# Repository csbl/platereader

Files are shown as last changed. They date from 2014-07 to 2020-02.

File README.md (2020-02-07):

## Miniaturized plate reader designs
This repository provides all the materials needed to assemble a miniaturized plate reader for measuring optical density in 96-well plates. 

Code is available at: https://github.com/csbl/PlateReaderCode

-- 
### File Descriptions
* Assembly Instructions.docx -- Instructions for assembling PCBs, loading code onto Arduinos, and running experiments.
* Parts List.xlsx -- Quantity, pricing, and availability information for all electrical and structural components.
* schematics
    + Frame_Drawings -- SolidWorks technical drawings for machining the aluminum frames.
    + PCBs -- Layout files for three printed circuit boards:  the emitter/detector layout boards (EmitterDetector), the controller shield for an Arduino Mega (MegaShield), and a breakout board for the XBee wireless chip (XBeeBreakoutBoard).
        - .pcb files for ExpressPCB software (http://expresspcb.com/).  We ordered our boards directly from this vendor using their free software.
        - To order boards from other vendors, we have included folders with Gerber files.  These files were provided by ExpressPCB.  Unfortunately, we have not ordered boards using the drawings, so we cannot guarantee their validity.  The file descriptions are:
            * .SLK = top silkscreen layer
            * .SMT = top solder mask layer
            * .TOP = top copper layer
            * .BOT = bottom copper layer
            * .SMB = bottom solder mask layer
            * .DRI = drill file
            * .OLN = board outline

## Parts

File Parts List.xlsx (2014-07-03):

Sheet: Total
ID | Part Description | Price per Part | Number Parts | TOTAL | Link
Emitter and Detector PCBs
1 | Emitter and Detector PCBs | $52.75 | 2 | $105.50 | Computed for 2 boards
2 | Phototransistors | $0.24 | 100 | $24.00 | http://www.digikey.com/product-search/en?x=0&y=0&lang=en&site=us&KeyWords=475-1080-ND
3 | Emitters | $0.65 | 100 | $65.00 | http://www.digikey.com/product-search/en?WT.z_header=search_go&lang=en&site=us&x=0&y=0&formaction=on
4 | Ribbon cable connectors | $0.84 | 4 | $3.36 | http://www.digikey.com/product-search/en?vendor=0&keywords=MKC14E-ND
5 | Ribbon cable (price per foot) | $0.65 | 4 | $2.60 | http://www.digikey.com/product-detail/en/3355%2F14%20100/MB14G-100-ND/1107667
6 | Multiplexers (for Emitter Detector PCBs) | $2.22 | 4 | $8.88 | http://www.digikey.com/product-detail/en/MAX4617CPE%2B/MAX4617CPE%2B-ND/1780285
7 | Ribbon cable connectors (mounted on boards) | $2.65 | 2 | $5.30 | http://www.digikey.com/product-search/en?vendor=0&keywords=MHB14K-ND
Arduino Mega Sheild
8 | Arduino Mega | $44.45 | 1 | $44.45
9 | MicroSD breakout board | $14.95 | 1 | $14.95 | https://www.adafruit.com/product/254
10 | RTC | $9.00 | 1 | $9.00 | https://www.adafruit.com/product/264
11 | AFE | $10.80 | 1 | $10.80 | http://www.digikey.com/product-detail/en/LMP90100MH%2FNOPB/LMP90100MH%2FNOPB-ND/2514654
12 | Chip for VR | $0.92 | 1 | $0.92 | http://www.digikey.com/product-detail/en/UA723CN/296-11104-5-ND/382232
13 | 4.99K resistor (VR) | $0.10 | 1 | $0.10 | http://www.digikey.com/product-detail/en/MFR-25FBF52-4K99/4.99KXBK-ND/13161
14 | 1.5 K resistor (VR) | $0.15 | 1 | $0.15 | http://www.digikey.com/product-detail/en/RNF14FTD1K50/RNF14FTD1K50CT-ND/1975030
15 | 4.3 resistor (VR) | $0.10 | 1 | $0.10 | http://www.digikey.com/product-detail/en/CFR-25JB-52-4R3/4.3QBK-ND/1831
16 | 2.15K resistor (VR) | $0.15 | 1 | $0.15 | http://www.digikey.com/product-detail/en/RNF14FTD2K15/RNF14FTD2K15CT-ND/1975040
17 | Capacitor (VR) | $0.30 | 1 | $0.30 | http://www.digikey.com/product-detail/en/K101K10X7RF5UH5/BC2657CT-ND/2356871
18 | Capacitor (VR) | $0.50 | 1 | $0.50 | http://www.digikey.com/product-search/en?WT.z_header=search_go&lang=en&site=us&x=0&y=0&formaction=on
19 | Power Cord | $12.30 | 1 | $12.30 | http://www.digikey.com/product-search/en?WT.z_header=search_go&lang=en&site=us&x=0&y=0&formaction=on
20 | Red LED | $0.50 | 1 | $0.50 | http://www.digikey.com/product-search/en?WT.z_header=search_go&lang=en&site=us&x=0&y=0&formaction=on
21 | Resistor 1 | $0.10 | 1 | $0.10 | http://www.digikey.com/product-detail/en/MFR-25FBF52-402R/402XBK-ND/12921
22 | Resistor 2 | $0.10 | 1 | $0.10 | http://www.digikey.com/product-detail/en/MFR-25FBF52-301R/301XBK-ND/12889
23 | Resistor 3 | $0.10 | 1 | $0.10 | http://www.digikey.com/product-detail/en/MFR-25FBF52-221R/221XBK-ND/12863
24 | Resistor 4 | $0.10 | 1 | $0.10 | http://www.digikey.com/product-detail/en/MFR-25FBF52-178R/178XBK-ND/12845
25 | SD card | $12.95 | 1 | $12.95 | https://www.sparkfun.com/products/11609
26 | MAX 4617 Multiplexer (Resistors) | $2.08 | 1 | $2.08 | http://www.digikey.com/product-detail/en/MAX4617CUE%2B/MAX4617CUE%2B-ND/1016407
27 | Ribbon cable connectors | $2.65 | 2 | $5.30 | http://www.digikey.com/product-search/en?WT.z_header=search_go&lang=en&site=us&x=0&y=0&formaction=on
28 | 200 resistor for LED | $0.08 | 1 | $0.08 | http://www.digikey.com/product-detail/en/CF14JT200R/CF14JT200RCT-ND/1830333
29 | 100K resistor (VR) | $0.44 | 1 | $0.44 | http://www.digikey.com/product-detail/en/HHV-25FR-52-100K/100KGACT-ND/2813157
30 | Female header for Xbee | $1.00 | 1 | $1.00 | https://www.sparkfun.com/products/8272
31 | Header (40 pins per strip) | $1.50 | 1 | $1.50 | https://www.sparkfun.com/products/116
32 | Power Switch | $1.50 | 1 | $1.50 | https://www.sparkfun.com/products/102
33 | Barrel Jack | $1.25 | 1 | $1.25 | https://www.sparkfun.com/products/119
34 | Xbee | $25.95 | 2 | $51.90 | https://www.sparkfun.com/products/11217
35 | Xbee PCB | $38.48 | 1 | $38.48
36 | Raspberry Pi | $39.95 | 1 | $39.95
 |  |  | TOTAL | $465.69

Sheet: Controller Board
ID | Part Description | Price per Part | Number Parts | TOTAL
1 | Arduino Mega | $44.45 | 1 | $44.45
2 | MicroSD breakout board | $14.95 | 1 | $14.95 | https://www.adafruit.com/product/254
3 | RTC | $9.00 | 1 | $9.00 | https://www.adafruit.com/product/264
4 | AFE | $10.80 | 1 | $10.80 | http://www.digikey.com/product-detail/en/LMP90100MH%2FNOPB/LMP90100MH%2FNOPB-ND/2514654
5 | Chip for VR | $0.92 | 1 | $0.92 | http://www.digikey.com/product-detail/en/UA723CN/296-11104-5-ND/382232
6 | 4.99K resistor (VR) | $0.10 | 1 | $0.10 | http://www.digikey.com/product-detail/en/MFR-25FBF52-4K99/4.99KXBK-ND/13161
7 | 1.5 K resistor (VR) | $0.15 | 1 | $0.15 | http://www.digikey.com/product-detail/en/RNF14FTD1K50/RNF14FTD1K50CT-ND/1975030
8 | 4.3 resistor (VR) | $0.10 | 1 | $0.10 | http://www.digikey.com/product-detail/en/CFR-25JB-52-4R3/4.3QBK-ND/1831
9 | 2.15K resistor (VR) | $0.15 | 1 | $0.15 | http://www.digikey.com/product-detail/en/RNF14FTD2K15/RNF14FTD2K15CT-ND/1975040
10 | Capacitor (VR) | $0.30 | 1 | $0.30 | http://www.digikey.com/product-detail/en/K101K10X7RF5UH5/BC2657CT-ND/2356871
11 | Capacitor (VR) | $0.50 | 1 | $0.50 | http://www.digikey.com/product-search/en?WT.z_header=search_go&lang=en&site=us&x=0&y=0&formaction=on
12 | Power Cord | $12.30 | 1 | $12.30 | http://www.digikey.com/product-search/en?WT.z_header=search_go&lang=en&site=us&x=0&y=0&formaction=on
13 | Red LED | $0.50 | 1 | $0.50 | http://www.digikey.com/product-search/en?WT.z_header=search_go&lang=en&site=us&x=0&y=0&formaction=on
14 | Resistor 1 | $0.10 | 1 | $0.10 | http://www.digikey.com/product-detail/en/MFR-25FBF52-402R/402XBK-ND/12921
15 | Resistor 2 | $0.10 | 1 | $0.10 | http://www.digikey.com/product-detail/en/MFR-25FBF52-301R/301XBK-ND/12889
16 | Resistor 3 | $0.10 | 1 | $0.10 | http://www.digikey.com/product-detail/en/MFR-25FBF52-221R/221XBK-ND/12863
17 | Resistor 4 | $0.10 | 1 | $0.10 | http://www.digikey.com/product-detail/en/MFR-25FBF52-178R/178XBK-ND/12845
18 | SD card | $12.95 | 1 | $12.95 | https://www.sparkfun.com/products/11609
19 | MAX 4617 Multiplexer (Resistors) | $2.08 | 1 | $2.08 | http://www.digikey.com/product-detail/en/MAX4617CUE%2B/MAX4617CUE%2B-ND/1016407
20 | Ribbon cable connectors | $2.65 | 2 | $5.30 | http://www.digikey.com/product-search/en?WT.z_header=search_go&lang=en&site=us&x=0&y=0&formaction=on
21 | 200 resistor for LED | $0.08 | 1 | $0.08 | http://www.digikey.com/product-detail/en/CF14JT200R/CF14JT200RCT-ND/1830333
22 | 100K resistor (VR) | $0.44 | 1 | $0.44 | http://www.digikey.com/product-detail/en/HHV-25FR-52-100K/100KGACT-ND/2813157
23 | Female header for Xbee | $1.00 | 1 | $1.00 | https://www.sparkfun.com/products/8272
24 | Header (40 pins per strip) | $1.50 | 1 | $1.50 | https://www.sparkfun.com/products/116
25 | Power Switch | $1.50 | 1 | $1.50 | https://www.sparkfun.com/products/102
26 | Barrel Jack | $1.25 | 1 | $1.25 | https://www.sparkfun.com/products/119
27 | Xbee | $25.95 | 1 | $25.95 | https://www.sparkfun.com/products/11217
28 | Xbee PCB | $38.48 | 1 | $38.48 |  | $382.36 for 100 boards
 |  |  |  | $185.15

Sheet: Aluminum Frame
ID | MccMaster-carr ID | Part Description | Price per Unit | Parts per Unit | Parts Needed Per Device | TOTAL
1 | 92185A996 | Type 316 Stainless Steel Socket Head Cap Screw, 10-32 Thread, 2" Length | $8.49 | 10 | 4 | $8.49
2 | 91249A161 | Plate machine screws 6-32 | $10.45 | 50 | 8 | $10.45
3 | 92001A281 | Wing nut 6-32 | $6.65 | 25 | 4 | $6.65
4 | 92510A446 | spacers 6-32 | $0.34 | 1 | 4 | $1.36
5 | 93135A304 | 3/8" 6-32 Nylon Screw | $0.27 | 1 | 4 | $1.08
6 | 93135A305 | 1/2" 6-32 Nylon Screw | $5.23 | 100 | 4 | $5.23
7 | 90295A380 | Nylon Washer no. 6 | $4.04 | 100 | 24 | $4.04
8 | 94639A299 | Nylon Spacer | $7.11 | 100 | 8 | $7.11
9 | 90107A101 | Metal Washers | $4.32 | 100 | 12 | $4.32
10 | 92949A148 | .5" 6-32 botton head | $4.63 | 100 | 8 | $4.63
 |  |  |  |  | TOTAL | $53.36

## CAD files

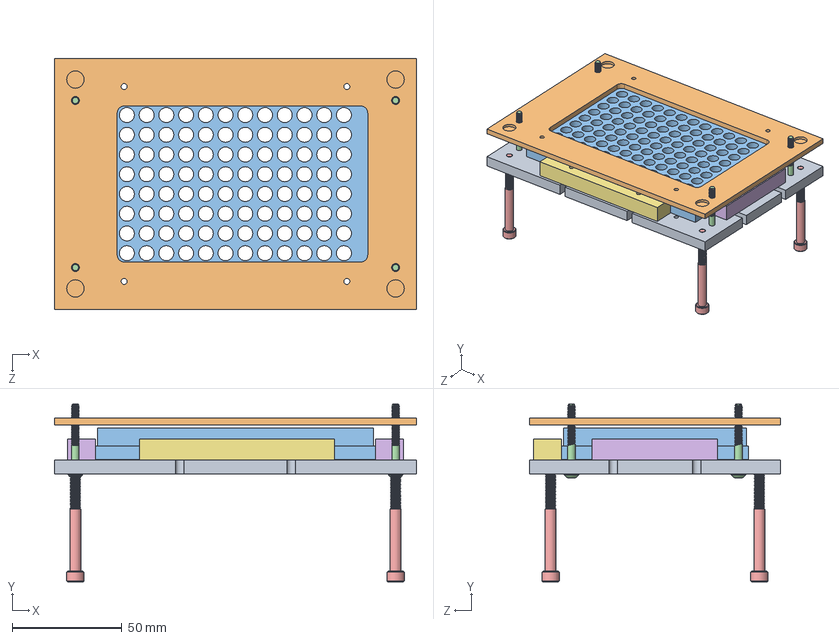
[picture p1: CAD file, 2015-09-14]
schematics/Frame_Drawings/Assem 96 well Plate.SLDASM
165.1 x 81.0 x 114.3 mm
Bottom Plate
Top Plate
96 Well plate
91255A155 Guide_Bolt x 4
92185A996 foot x 4
Side rails amr x 2
Back Stop amr

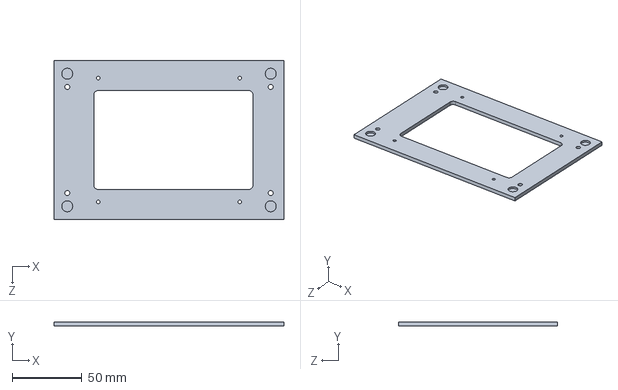
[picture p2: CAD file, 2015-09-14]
schematics/Frame_Drawings/Top Plate.SLDPRT
165.1 x 3.17 x 114.3 mm

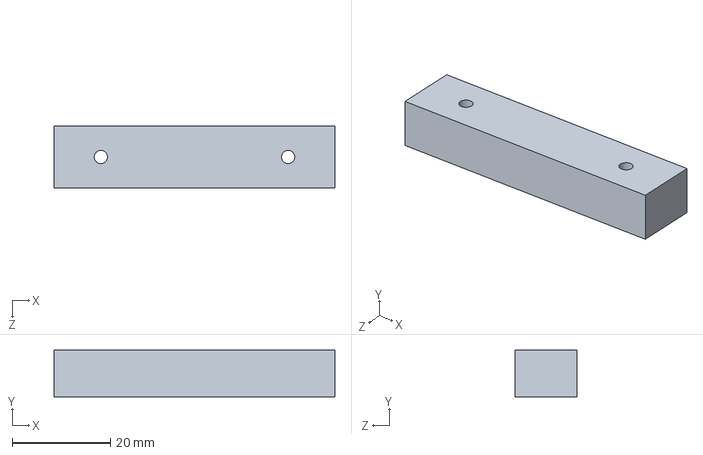
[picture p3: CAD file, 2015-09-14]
schematics/Frame_Drawings/Side rails.SLDPRT
57.1 x 9.53 x 12.7 mm

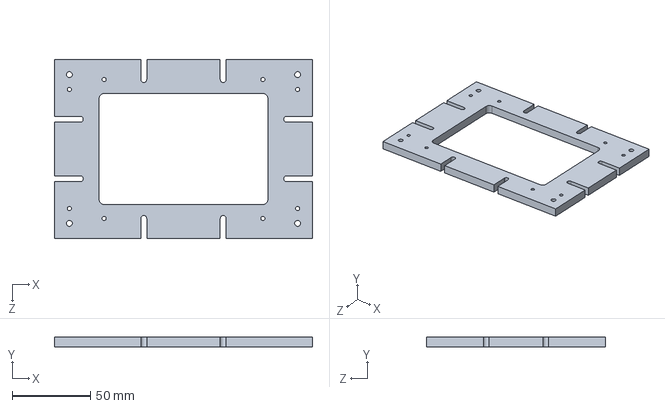
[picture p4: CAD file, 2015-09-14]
schematics/Frame_Drawings/Bottom Plate.SLDPRT
165.1 x 6.35 x 114.3 mm

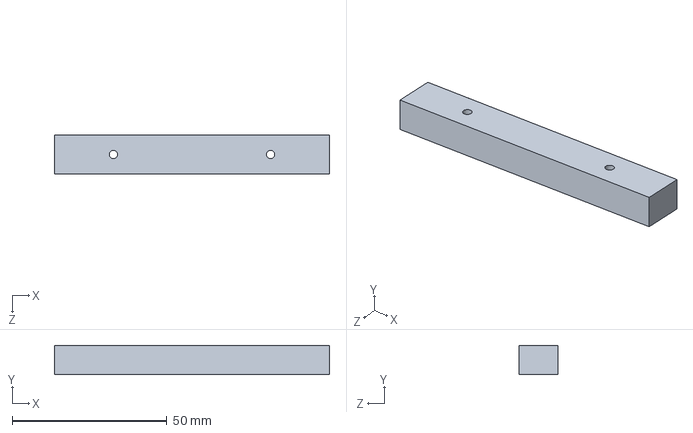
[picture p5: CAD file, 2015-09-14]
schematics/Frame_Drawings/Back Stop.SLDPRT
88.9 x 9.53 x 12.7 mm

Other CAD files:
schematics/Frame_Drawings/Back Stop.SLDDRW
schematics/Frame_Drawings/Bottom Plate.SLDDRW
schematics/Frame_Drawings/Side rails.SLDDRW
schematics/Frame_Drawings/Top Plate.SLDDRW

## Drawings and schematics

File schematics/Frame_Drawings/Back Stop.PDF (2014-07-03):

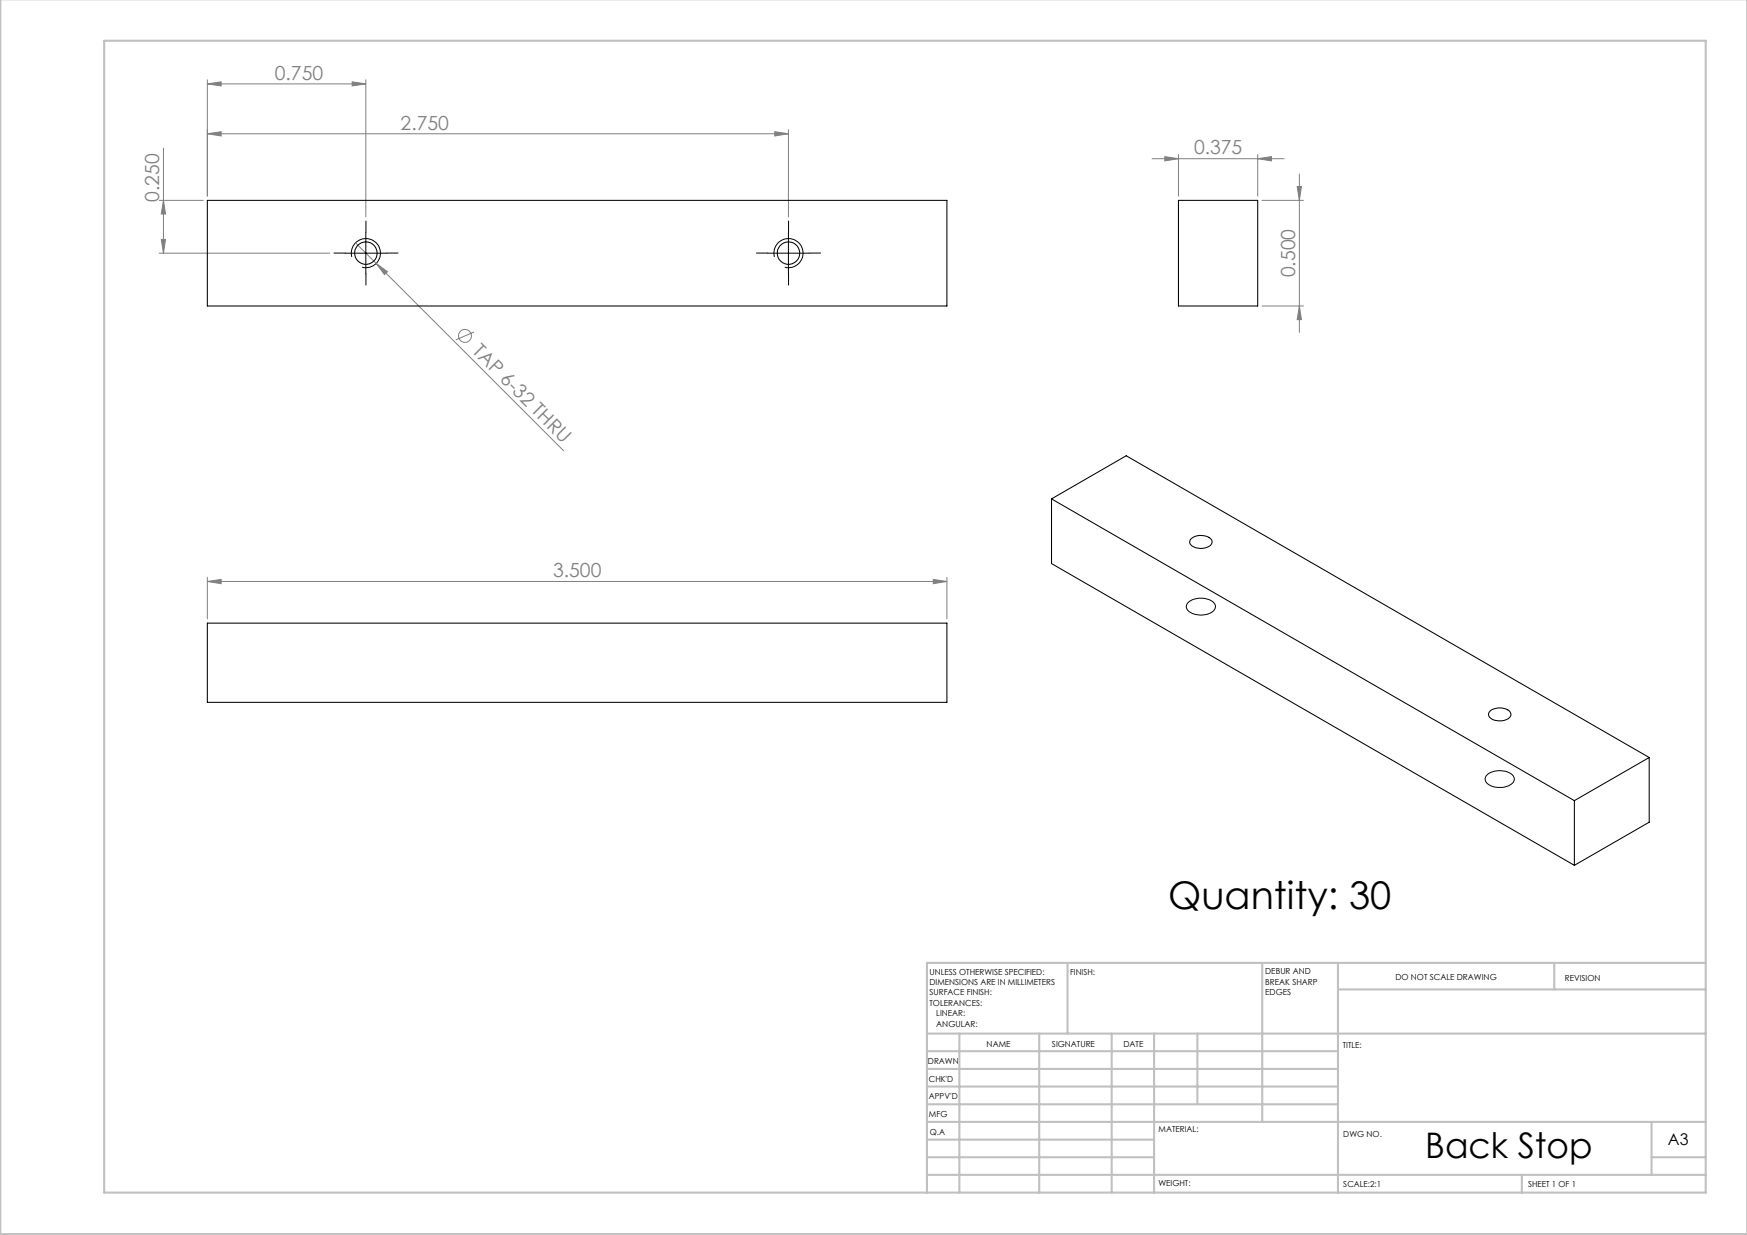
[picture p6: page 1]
TAP 6-32 THRU; Quantity: 30; SCALE:2:1; SHEET 1 OF 1; DO NOT SCALE DRAWING; REVISION; DEBUR AND BREAK SHARP; UNLESS OTHERWISE SPECIFIED:; FINISH:

DIMENSIONS ARE IN MILLIMETERS
SURFACE FINISH:
TOLERANCES:
LINEAR:
ANGULAR:

NAME | SIGNATURE | DATE | | | | TITLE:
Q.A | | | | MATERIAL: | Back Stop WEIGHT: DWG NO. | A3

DRAWN
CHK'D
APPV'D
MFG

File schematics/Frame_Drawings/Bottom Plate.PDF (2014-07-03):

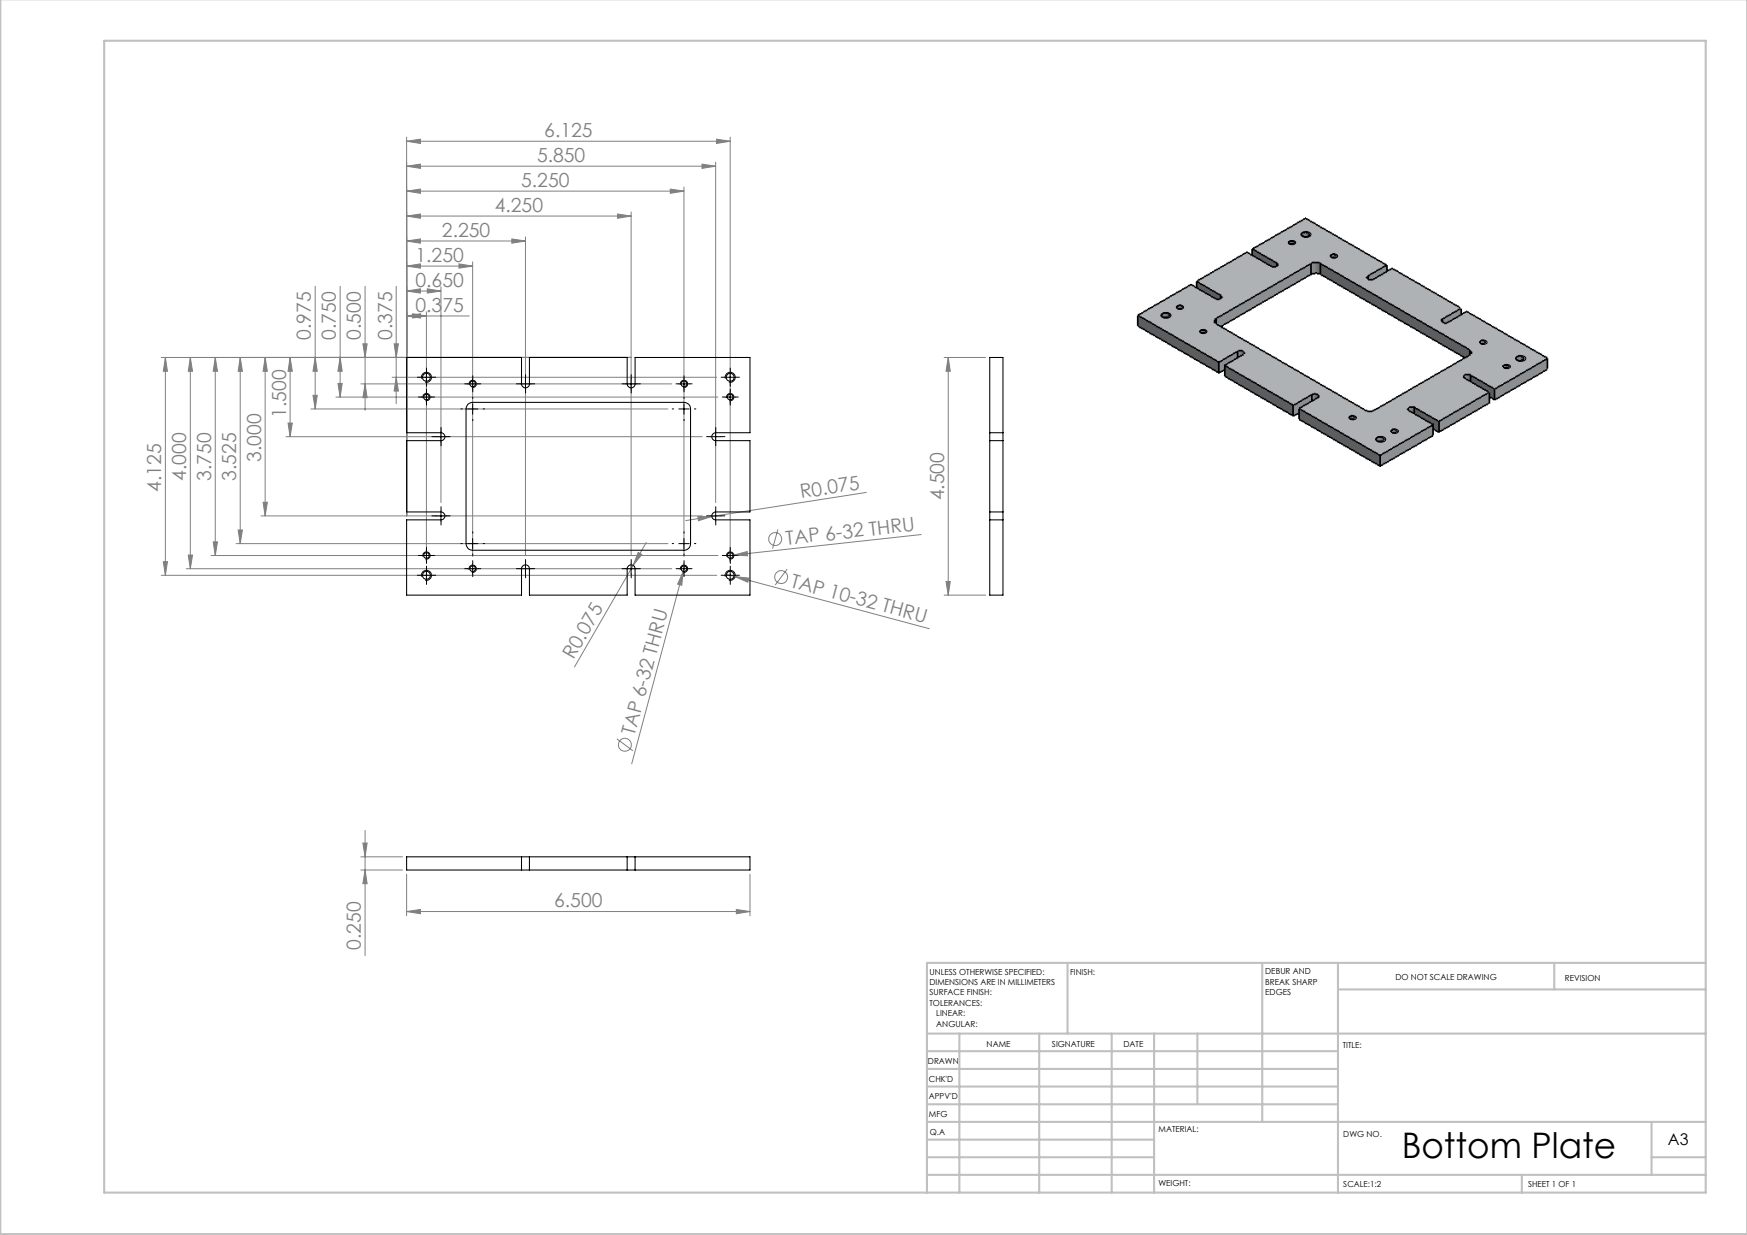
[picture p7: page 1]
TAP 6-32 THRU; TAP 10-32 THRU; SCALE:1:2; SHEET 1 OF 1; DO NOT SCALE DRAWING; REVISION; DEBUR AND BREAK SHARP; UNLESS OTHERWISE SPECIFIED:; FINISH:

DIMENSIONS ARE IN MILLIMETERS
SURFACE FINISH:
TOLERANCES:
LINEAR:
ANGULAR:

NAME | SIGNATURE | DATE | | | | TITLE:
Q.A | | | | MATERIAL: | Bottom Plate WEIGHT: DWG NO. | A3

DRAWN
CHK'D
APPV'D
MFG

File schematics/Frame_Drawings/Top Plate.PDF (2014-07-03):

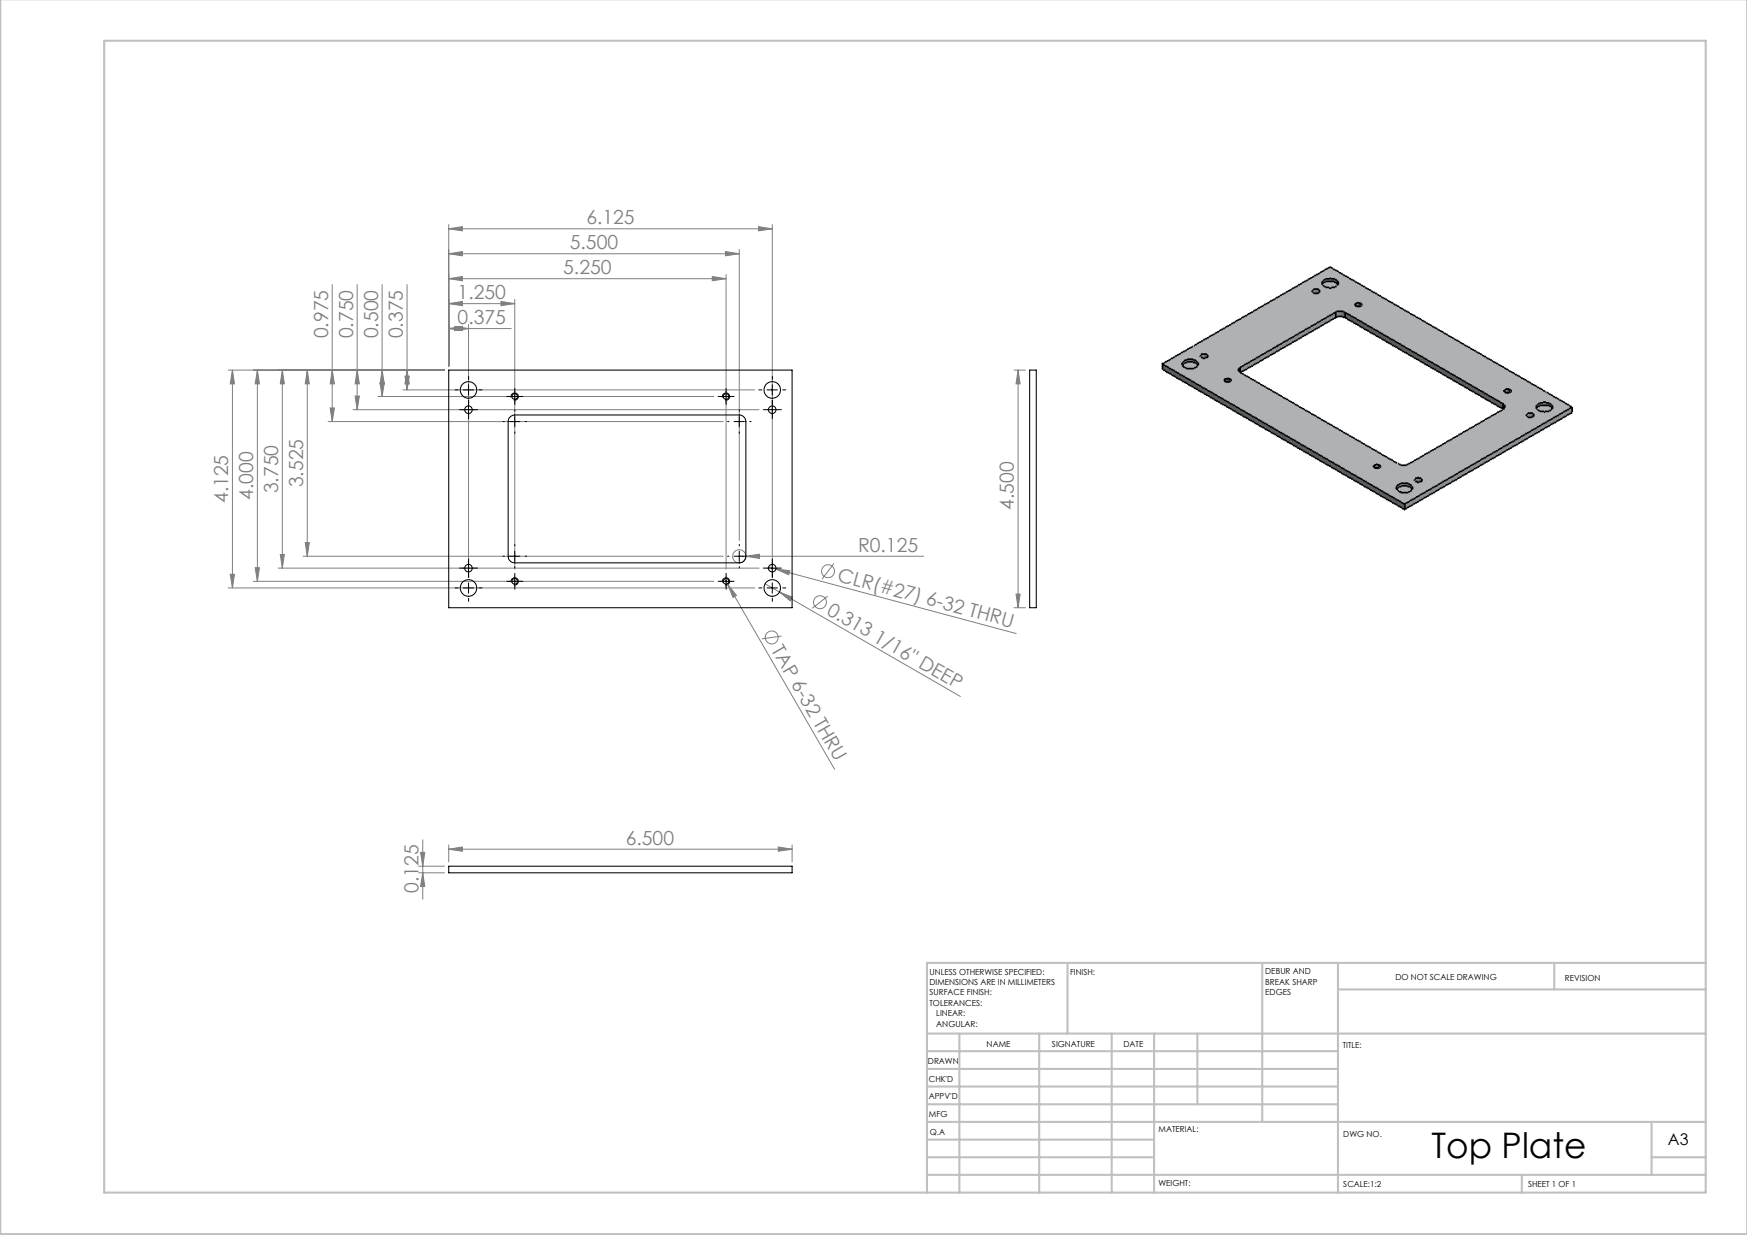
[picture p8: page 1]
TAP 6-32 THRU; 0.313 1/16" DEEP; CLR(#27) 6-32 THRU; SCALE:1:2; SHEET 1 OF 1; DO NOT SCALE DRAWING; REVISION; DEBUR AND BREAK SHARP; UNLESS OTHERWISE SPECIFIED:; FINISH:

DIMENSIONS ARE IN MILLIMETERS
SURFACE FINISH:
TOLERANCES:
LINEAR:
ANGULAR:

NAME | SIGNATURE | DATE | | | | TITLE:
Q.A | | | | MATERIAL: | Top Plate WEIGHT: DWG NO. | A3

DRAWN
CHK'D
APPV'D
MFG

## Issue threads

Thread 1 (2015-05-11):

Please add the instructions for frame assembly

chiffa, 2015-05-11:
Please, consider adding instructions for the metal frame assembly.

pauljensen, 2015-05-15:
@BonnieDougherty has updated the assembly instructions with information on the metal frame.  The frame parts are included in "Parts List.xlsx".

Good luck!

chiffa, 2015-05-15:
Thank you!

Closed 2015-05-15.

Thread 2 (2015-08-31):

.stl or .sldprt files for frame?

galazkaj, 2015-08-31:
Great project! I would like to 3D print the frame with plastic. Could you post a .stl or .sldprt file. Thanks!

pauljensen, 2015-09-14:
These files have been posted.  Thanks for your interest!

Closed 2015-09-14.

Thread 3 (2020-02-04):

Software Availability

TheLostLambda, 2020-02-04:
Hello!
I've just read the paper describing this device in The Journal of Laboratory Automation which linked me here for the software for both the reader and database servers.

Alas, I cannot find any of the software here. Where should I look?

BonnieDougherty, 2020-02-07:
The schematics for building a reader are located at https://github.com/csbl/platereader and the code is located in a separate repository at https://github.com/csbl/PlateReaderCode.

Closed 2020-02-07.

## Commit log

2014-07-03 initial import
    [Back Stop.SLDDRW, Bottom Plate.SLDDRW, Parts List.xlsx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]
2014-07-03 added XBee gerbers
2015-05-15 updated assembly instructions for metal frame
2015-05-15 removed docx assembly instructions
2015-09-14 Add SolidWorks CAD Files
    [Assem 96 well Plate.SLDASM, Back Stop.SLDPRT, Bottom Plate.SLDPRT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]
